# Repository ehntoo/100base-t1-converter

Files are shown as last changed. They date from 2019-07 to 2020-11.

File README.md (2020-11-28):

# 100base-t1-converter

This project provides a media converter for connecting 100Base-TX ethernet to
100Base-T1 (Automotive Ethernet) networks, using an NXP TJA1101 PHY. This part
doesn't have a whole lot of officially-available documentation, but is
significantly cheaper than the previous-generation TJA1100. Sufficient
information to use the chip in a design was assembled from various NXP (and
other) schematics online, such as the NXP schematics for the S32K148-T-BOX EVK.

Additional information for debugging was sourced from the Linux TJA11xx PHY
drivers.

The 100Base-TX PHY used is a CoreChips SR8201F (Realtek RTL8201F compatible),
sourceable from LCSC for ~$0.25 in reasonable quantities.

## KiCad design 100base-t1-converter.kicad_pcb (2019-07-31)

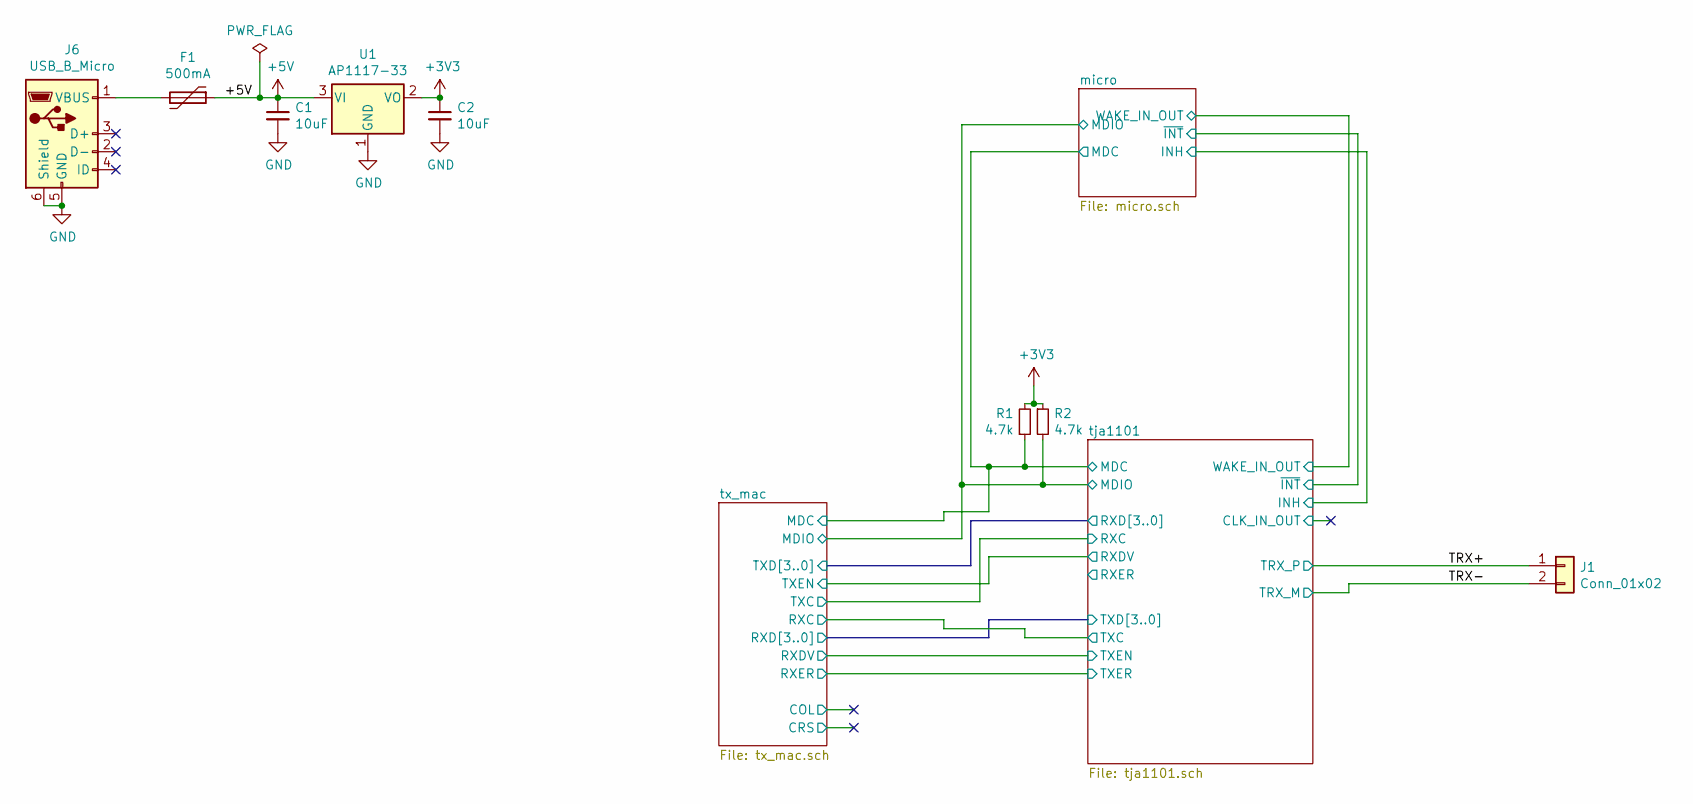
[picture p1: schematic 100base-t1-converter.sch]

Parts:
C1, C2: 10uF; C_0603_1608Metric_Pad1.05x0.95mm_HandSolder
F1: 500mA; Fuse_0805_2012Metric_Pad1.15x1.40mm_HandSolder
J1: Conn_01x02; SIP-2
J6: USB_B_Micro; LCSC_C77238
R1, R2: 4.7k; R_0603_1608Metric_Pad1.05x0.95mm_HandSolder
U1: AP1117-33; SOT-223-3_TabPin2

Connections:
+3V3: C2.1, R1.2, R2.1, U1.2 (VO); also elsewhere on the board
+5V: C1.1, F1.1, U1.3 (VI); also elsewhere on the board
/TRX+: J1.1; also elsewhere on the board
/TRX-: J1.2; also elsewhere on the board
/micro/MDC: R1.1; also elsewhere on the board
/micro/MDIO: R2.2; also elsewhere on the board
GND: C1.2, C2.2, J6.5 (GND), J6.6 (Shield), U1.1 (GND); also elsewhere on the board
unnamed: F1.2, J6.1 (VBUS)

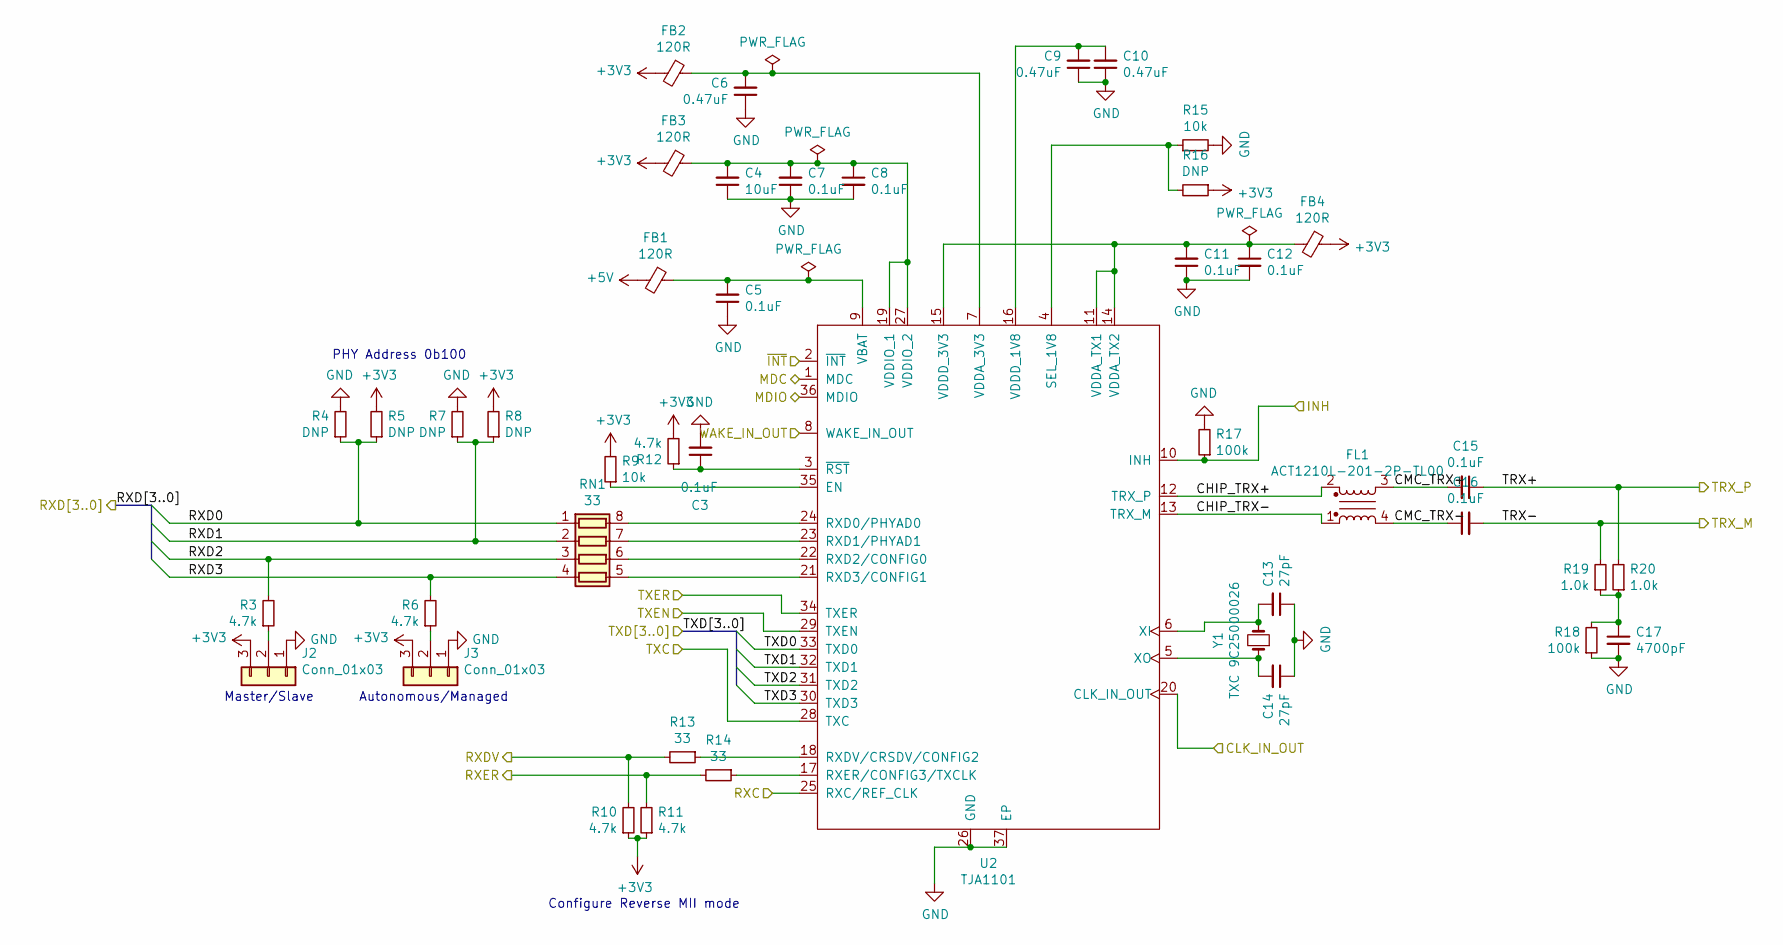
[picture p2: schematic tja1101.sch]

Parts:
C3, C5, C7, C8, C11, C12, C15, C16: 0.1uF; C_0603_1608Metric_Pad1.05x0.95mm_HandSolder
C4: 10uF; C_0603_1608Metric_Pad1.05x0.95mm_HandSolder
C6, C9, C10: 0.47uF; C_0603_1608Metric_Pad1.05x0.95mm_HandSolder
C13, C14: 27pF; C_0603_1608Metric_Pad1.05x0.95mm_HandSolder
C17: 4700pF; C_0603_1608Metric_Pad1.05x0.95mm_HandSolder
FB1, FB2, FB3, FB4: 120R; L_0603_1608Metric_Pad1.05x0.95mm_HandSolder
FL1: ACT1210L-201-2P-TL00; SOIC-4
J2, J3: Conn_01x03; PinSocket_1x03_P2.54mm_Vertical
R3, R6, R10, R11, R12: 4.7k; R_0603_1608Metric_Pad1.05x0.95mm_HandSolder
R4, R5, R7, R8, R16: DNP; R_0603_1608Metric_Pad1.05x0.95mm_HandSolder
R9, R15: 10k; R_0603_1608Metric_Pad1.05x0.95mm_HandSolder
R13, R14: 33; R_0603_1608Metric_Pad1.05x0.95mm_HandSolder
R17, R18: 100k; R_0603_1608Metric_Pad1.05x0.95mm_HandSolder
R19, R20: 1.0k; R_0603_1608Metric_Pad1.05x0.95mm_HandSolder
RN1: 33; R_Array_Convex_Reversed_4x0603
U2: TJA1101; QFN-36-1EP_6x6mm_P0.5mm_EP4.1x4.1mm_ThermalVias
Y1: TXC 9C25000026; Crystal_SMD_HC49-SD_HandSoldering

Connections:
+3V3: FB2.2, FB3.2, FB4.1, J2.3, J3.3, R5.2, R8.2, R9.2, R10.1, R11.1, R12.2, R16.1; also elsewhere on the board
+5V: FB1.2; also elsewhere on the board
/TRX+: C15.1, R20.2; also elsewhere on the board
/TRX-: C16.2, R19.2; also elsewhere on the board
/micro/INH: R17.1, U2.10 (INH); also elsewhere on the board
/micro/MDC: U2.1 (MDC); also elsewhere on the board
/micro/MDIO: U2.36 (MDIO); also elsewhere on the board
/micro/WAKE_IN_OUT: U2.8 (WAKE_IN_OUT); also elsewhere on the board
/micro/~INT: U2.2 (~INT); also elsewhere on the board
/tja1101/CHIP_TRX+: FL1.2, U2.12 (TRX_P)
/tja1101/CHIP_TRX-: FL1.1, U2.13 (TRX_M)
/tja1101/CLK_IN_OUT: U2.20 (CLK_IN_OUT)
/tja1101/CMC_TRX+: C15.2, FL1.3
/tja1101/CMC_TRX-: C16.1, FL1.4
/tja1101/RXC: U2.25 (RXC/REF_CLK); also elsewhere on the board
/tja1101/RXD0: R4.1, R5.1, RN1.1 (R1.1); also elsewhere on the board
/tja1101/RXD1: R7.1, R8.1, RN1.2 (R2.1); also elsewhere on the board
/tja1101/RXD2: R3.2, RN1.3 (R3.1); also elsewhere on the board
/tja1101/RXD3: R6.2, RN1.4 (R4.1); also elsewhere on the board
/tja1101/RXDV: R10.2, R13.2; also elsewhere on the board
/tja1101/RXER: R11.2, R14.2
/tx_mac/RXC: U2.28 (TXC); also elsewhere on the board
/tx_mac/RXD0: U2.33 (TXD0); also elsewhere on the board
/tx_mac/RXD1: U2.32 (TXD1); also elsewhere on the board
/tx_mac/RXD2: U2.31 (TXD2); also elsewhere on the board
/tx_mac/RXD3: U2.30 (TXD3); also elsewhere on the board
/tx_mac/RXDV: U2.29 (TXEN); also elsewhere on the board
/tx_mac/RXER: U2.34 (TXER); also elsewhere on the board
GND: C3.2, C4.1, C5.1, C6.1, C7.1, C8.2, C9.1, C10.1, C11.1, C12.2, C13.1, C14.1, C17.2, J2.1, J3.1, R4.2, R7.2, R15.2, R17.2, R18.1, U2.26 (GND), U2.37 (EP); also elsewhere on the board
unnamed: C3.1, R12.1, U2.3 (~RST)
unnamed: C4.2, C7.2, C8.1, FB3.1, U2.19 (VDDIO_1), U2.27 (VDDIO_2)
unnamed: C5.2, FB1.1, U2.9 (VBAT)
unnamed: C6.2, FB2.1, U2.7 (VDDA_3V3)
unnamed: C9.2, C10.2, U2.16 (VDDD_1V8)
unnamed: C11.2, C12.1, FB4.2, U2.11 (VDDA_TX1), U2.14 (VDDA_TX2), U2.15 (VDDD_3V3)
unnamed: C13.2, U2.6 (XI), Y1.2
unnamed: C14.2, U2.5 (XO), Y1.1
unnamed: C17.1, R18.2, R19.1, R20.1
unnamed: J2.2, R3.1
unnamed: J3.2, R6.1
unnamed: R9.1, U2.35 (EN)
unnamed: R13.1, U2.18 (RXDV/CRSDV/CONFIG2)
unnamed: R14.1, U2.17 (RXER/CONFIG3/TXCLK)
unnamed: R15.1, R16.2, U2.4 (SEL_1V8)
unnamed: RN1.5 (R4.2), U2.21 (RXD3/CONFIG1)
unnamed: RN1.6 (R3.2), U2.22 (RXD2/CONFIG0)
unnamed: RN1.7 (R2.2), U2.23 (RXD1/PHYAD1)
unnamed: RN1.8 (R1.2), U2.24 (RXD0/PHYAD0)

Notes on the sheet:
Configure Reverse MII mode
PHY Address 0b100
Master/Slave
Autonomous/Managed

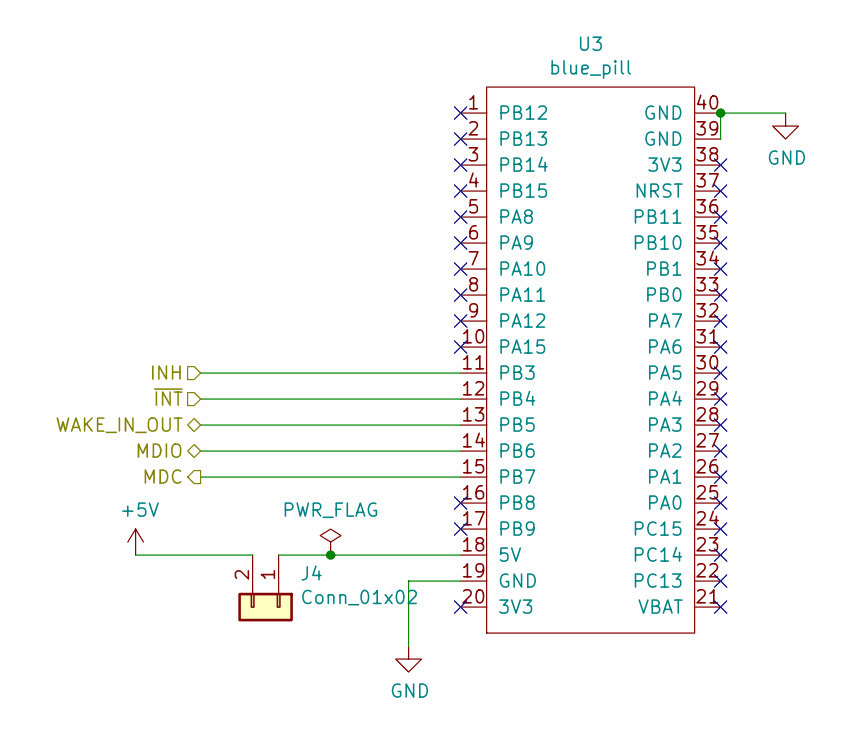
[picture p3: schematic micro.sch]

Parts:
J4: Conn_01x02; PinSocket_1x02_P2.54mm_Vertical
U3: blue_pill; DIP-40_W15.24mm

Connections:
+5V: J4.2; also elsewhere on the board
/micro/INH: U3.11 (PB3); also elsewhere on the board
/micro/MDC: U3.15 (PB7); also elsewhere on the board
/micro/MDIO: U3.14 (PB6); also elsewhere on the board
/micro/WAKE_IN_OUT: U3.13 (PB5); also elsewhere on the board
/micro/~INT: U3.12 (PB4); also elsewhere on the board
GND: U3.19 (GND), U3.39 (GND), U3.40 (GND); also elsewhere on the board
unnamed: J4.1, U3.18 (5V)

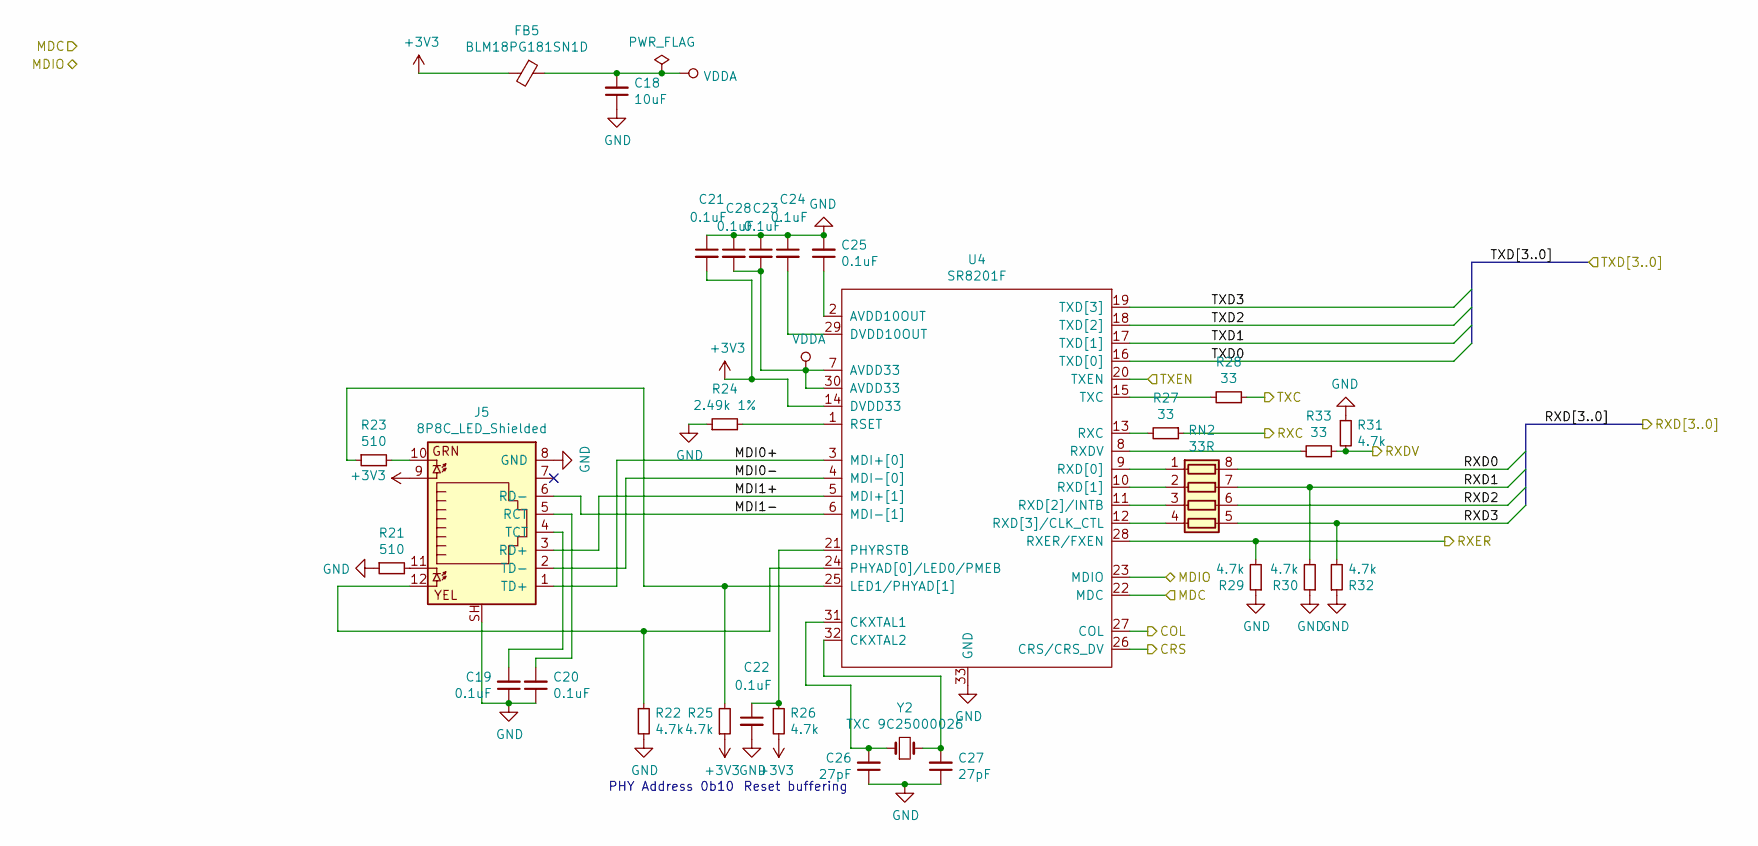
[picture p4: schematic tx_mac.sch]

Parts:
C18: 10uF; C_0603_1608Metric_Pad1.05x0.95mm_HandSolder
C19, C20, C21, C22, C23, C24, C25, C28: 0.1uF; C_0603_1608Metric_Pad1.05x0.95mm_HandSolder
C26, C27: 27pF; C_0603_1608Metric_Pad1.05x0.95mm_HandSolder
FB5: BLM18PG181SN1D; L_0603_1608Metric_Pad1.05x0.95mm_HandSolder
J5: 8P8C_LED_Shielded; RJ45_Hanrun_HR911105A
R21, R23: 510; R_0603_1608Metric_Pad1.05x0.95mm_HandSolder
R22, R25, R26, R29, R30, R31, R32: 4.7k; R_0603_1608Metric_Pad1.05x0.95mm_HandSolder
R24: 2.49k 1%; R_0603_1608Metric_Pad1.05x0.95mm_HandSolder
R27, R28, R33: 33; R_0603_1608Metric_Pad1.05x0.95mm_HandSolder
RN2: 33R; R_Array_Convex_Reversed_4x0603
U4: SR8201F; QFN-32-1EP_5x5mm_P0.5mm_EP3.6x3.6mm_ThermalVias
Y2: TXC 9C25000026; Crystal_SMD_HC49-SD_HandSoldering

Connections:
+3V3: C21.2, FB5.2, J5.9, R25.1, R26.2, U4.14 (DVDD33); also elsewhere on the board
/micro/MDC: U4.22 (MDC); also elsewhere on the board
/micro/MDIO: U4.23 (MDIO); also elsewhere on the board
/tja1101/RXC: R28.1; also elsewhere on the board
/tja1101/RXD0: U4.16 (TXD[0]); also elsewhere on the board
/tja1101/RXD1: U4.17 (TXD[1]); also elsewhere on the board
/tja1101/RXD2: U4.18 (TXD[2]); also elsewhere on the board
/tja1101/RXD3: U4.19 (TXD[3]); also elsewhere on the board
/tja1101/RXDV: U4.20 (TXEN); also elsewhere on the board
/tx_mac/COL: U4.27 (COL)
/tx_mac/CRS: U4.26 (CRS/CRS_DV)
/tx_mac/MDI0+: J5.1 (TD+), U4.3 (MDI+[0])
/tx_mac/MDI0-: J5.2 (TD-), U4.4 (MDI-[0])
/tx_mac/MDI1+: J5.3 (RD+), U4.5 (MDI+[1])
/tx_mac/MDI1-: J5.6 (RD-), U4.6 (MDI-[1])
/tx_mac/RXC: R27.1; also elsewhere on the board
/tx_mac/RXD0: RN2.8 (R1.2); also elsewhere on the board
/tx_mac/RXD1: R30.2, RN2.7 (R2.2); also elsewhere on the board
/tx_mac/RXD2: RN2.6 (R3.2); also elsewhere on the board
/tx_mac/RXD3: R32.2, RN2.5 (R4.2); also elsewhere on the board
/tx_mac/RXDV: R31.2, R33.1; also elsewhere on the board
/tx_mac/RXER: R29.2, U4.28 (RXER/FXEN); also elsewhere on the board
GND: C18.1, C19.1, C20.1, C21.1, C22.2, C23.1, C24.1, C25.2, C26.1, C27.1, C28.1, J5.8 (GND), J5.SH, R21.1, R22.2, R24.1, R29.1, R30.1, R31.1, R32.1, U4.33 (GND); also elsewhere on the board
unnamed: C19.2, J5.4 (TCT)
unnamed: C20.2, J5.5 (RCT)
unnamed: C22.1, R26.1, U4.21 (PHYRSTB)
unnamed: C24.2, U4.29 (DVDD10OUT)
unnamed: C25.1, U4.2 (AVDD10OUT)
unnamed: C26.2, U4.31 (CKXTAL1), Y2.1
unnamed: C27.2, U4.32 (CKXTAL2), Y2.2
unnamed: J5.10, R23.2
unnamed: J5.11, R21.2
unnamed: J5.12, R22.1, U4.24 (PHYAD[0]/LED0/PMEB)
unnamed: R23.1, R25.2, U4.25 (LED1/PHYAD[1])
unnamed: R24.2, U4.1 (RSET)
unnamed: R27.2, U4.13 (RXC)
unnamed: R28.2, U4.15 (TXC)
unnamed: R33.2, U4.8 (RXDV)
unnamed: RN2.1 (R1.1), U4.9 (RXD[0])
unnamed: RN2.2 (R2.1), U4.10 (RXD[1])
unnamed: RN2.3 (R3.1), U4.11 (RXD[2]/INTB)
unnamed: RN2.4 (R4.1), U4.12 (RXD[3]/CLK_CTL)
VDDA: C18.2, C23.2, C28.2, FB5.1, U4.7 (AVDD33), U4.30 (AVDD33)

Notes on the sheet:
PHY Address 0b10
Reset buffering

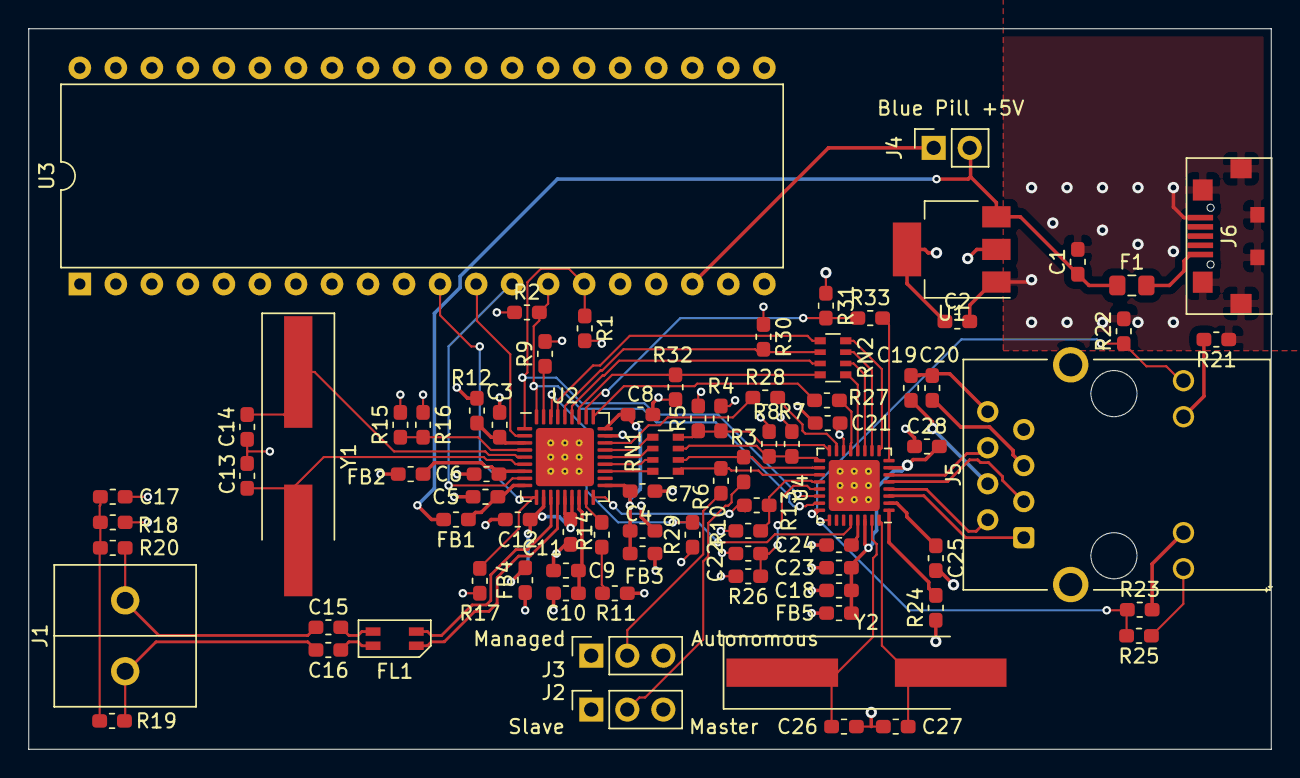
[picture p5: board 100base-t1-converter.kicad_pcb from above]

Board: 4 copper layers, 87.6 x 50.8 mm, 82 parts (0 on the bottom side), 73 nets.

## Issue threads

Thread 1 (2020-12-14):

How to config the two phys

fxj000, 2020-12-14:
hi, ehntoo,
How are you!
I am very happy to see you put this a good project. and I already draw a board, very similar with yours.
I used TJA1100 and LAN8710. but I don't know how to config the two PHYs, or do not need to config them any more? but so far it does not work. I am very sad.
This is my email: fxj460@163.com.  please kind to give me a hand. thank you very much.
Please reach out me and I can send my project file to you. Thank you.

ehntoo, 2020-12-29:
Hi, sorry to have missed this until now. The PHYs are both configured with strap resistors - with the TJA1100 (or TJA1101) placed into reverse MII mode, there should (theoretically) be no need to do any additional configuration over MII. Check out Table 10 in the TJA1100 datasheet for the necessary straps on that chip: https://www.nxp.com/docs/en/data-sheet/TJA1100.pdf

For the TJA1101 used here, I gathered the same information from a smattering of different schematics I found.

Good luck with your project!

fxj000, 2020-12-29:
Thank you so much for your help. I got it!

Closed 2020-12-29.

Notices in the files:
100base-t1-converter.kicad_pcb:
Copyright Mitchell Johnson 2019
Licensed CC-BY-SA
